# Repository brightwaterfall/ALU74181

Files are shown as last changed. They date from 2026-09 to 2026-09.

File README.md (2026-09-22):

  

# Tiny Tapeout — 74181 4-bit ALU

Digital Verilog **74181-style 4-bit ALU** for Tiny Tapeout (SKY130 / LibreLane).

**Repo:** https://github.com/brightwaterfall/ALU74181

- [Project documentation](docs/info.md)
- [Reproduce the flow](WALKTHROUGH.md)
- [Test PCB (auto S0–S3)](pcb/README.md)

## Status

| Check | Result |
|---|---|
| RTL cocotb (`test`) | Passing on GitHub Actions |
| GDS harden + precheck + GL test | Passing |
| Tagged release with GDS | See [Releases](https://github.com/brightwaterfall/ALU74181/releases) |

## Pin map

| Port | Signal |
|---|---|
| `ui_in[3:0]` | A[3:0] |
| `ui_in[7:4]` | B[3:0] |
| `uio_in[3:0]` | S[3:0] |
| `uio_in[4]` | M (1=logic, 0=arithmetic) |
| `uio_in[5]` | Cn_n (active-low carry in) |
| `uo_out[3:0]` | F[3:0] |
| `uo_out[4]` | AeqB |
| `uo_out[5]` | P_n |
| `uo_out[6]` | G_n |
| `uo_out[7]` | Cn4_n |

Top module: `tt_um_brightwaterfall_alu74181`

## Quick test

```bash
cd test
pip install -r requirements.txt
make
```

## What is Tiny Tapeout?

https://tinytapeout.com

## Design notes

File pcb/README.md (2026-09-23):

# 74181 ALU test PCB

Auto-exerciser for the Tiny Tapeout **74181 ALU** chip (`tt_um_brightwaterfall_alu74181`).

## Board preview

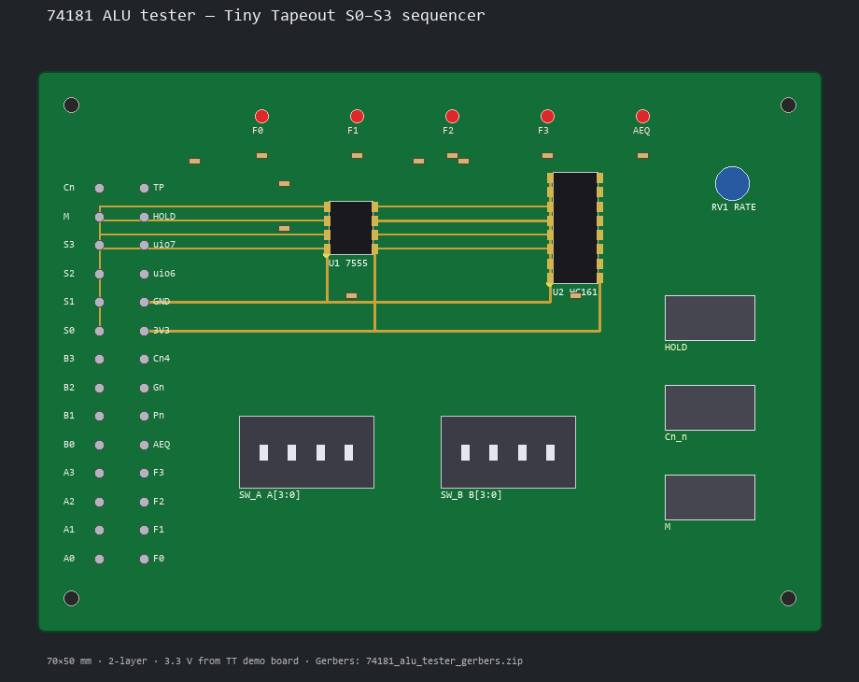
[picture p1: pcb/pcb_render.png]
PCB top view


## What it does

With **A**, **B**, **M**, and **Cn_n** on switches:

1. **7555/555** clocks a **74HC161**
2. **Q0–Q3 → S0–S3**
3. S runs **0→1→…→15→0…** (every function, one after another)
4. LEDs show **F[3:0]** and **AeqB**
5. **HOLD** freezes the current S value

Power and ground come from the **Tiny Tapeout demo board** (3.3 V). This PCB is an optional daughter / header harness — it does not replace the TT demo board.

## Fabrication (Gerbers ready)

| File | Purpose |
|---|---|
| **[74181_alu_tester_gerbers.zip](74181_alu_tester_gerbers.zip)** | Upload to JLCPCB / PCBWay |
| **[pcb_render.png](pcb_render.png)** | Top-view preview |
| [gerbers/](gerbers/) | Unpacked Gerber + Excellon |
| [generate_board.py](generate_board.py) | Regenerate Gerbers + preview (`py -3 generate_board.py`) |

**Board:** 70×50 mm · 2-layer · 1.6 mm · HASL · min track 0.25 mm

## Design docs

| File | Purpose |
|---|---|
| [BRINGUP.md](BRINGUP.md) | Power-on / usage |
| [SCHEMATIC.md](SCHEMATIC.md) | Net / wiring |
| [schematic_sequencer.svg](schematic_sequencer.svg) | Block schematic |
| [bom.csv](bom.csv) | BOM + LCSC hints |
| [connections.csv](connections.csv) | Header ↔ TT pins |
| `74181_alu_tester.kicad_pro` / `.kicad_sch` / `.kicad_pcb` | KiCad project shell (outline + notes) |

## Viewer (chip layout)

GitHub Pages + TT viewer: https://brightwaterfall.github.io/ALU74181/

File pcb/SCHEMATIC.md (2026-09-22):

# Schematic — 74181 ALU auto-S sequencer

Supply: **3V3** / **GND** from Tiny Tapeout demo board. All logic **74HC** @ 3.3 V.

## 1. Rate clock (555 astable)

| Ref | Value | Notes |
|-----|---|---|
| U1 | NE555 (or ICM7555) | Astable |
| R1 | 10 kΩ | |
| RV1 | 100 kΩ pot | Speed adjust |
| R2 | 10 kΩ | |
| C1 | 10 µF | ~0.5–10 Hz depending on pot |
| C2 | 100 nF | Control pin bypass |

Wiring (standard astable): discharge/threshold via R1+RV1/R2, C1 to GND, OUT → counter CLK.

## 2. S0–S3 sequencer (74HC161)

| Pin | Connection |
|-----|---|
| VCC / GND | 3V3 / GND |
| CLK | U1 OUT |
| ENT, ENP | 3V3 (count enable) |
| /LOAD | 3V3 (never parallel-load) |
| /CLR | 3V3 (no reset; free run 0–15) |
| A,B,C,D load inputs | GND |
| Q0 | **S0** → `uio[0]` |
| Q1 | **S1** → `uio[1]` |
| Q2 | **S2** → `uio[2]` |
| Q3 | **S3** → `uio[3]` |
| RCO | NC |

**HOLD** test point: pull **ENP** to GND through a switch to freeze S.

Sequence: `S = 0,1,2,…,15,0,…` — each value is one ALU function select, one after another.

## 3. Static ALU inputs (switches)

| Control | Destination | Default |
|---|---|---|
| DIP4 SW_A | `ui[0:3]` = A0…A3 | user |
| DIP4 SW_B | `ui[4:7]` = B0…B3 | user |
| SPDT SW_M | `uio[4]` = M | 3V3 = logic |
| SPDT SW_CN | `uio[5]` = Cn_n | 3V3 = carry inactive |

Each switch line: 10 kΩ pull-down to GND; switch to 3V3 closes = logic 1  
(or DIP with common GND and pull-ups — same idea). Use **10 kΩ** pull-downs + switch-to-3V3 for clarity.

`uio[6]`, `uio[7]`: tie to GND on the PCB.

## 4. Result LEDs (from chip)

| Source | Series R | LED |
|---|---|-----|
| `uo[0]` F0 | 330 Ω | LED0 |
| `uo[1]` F1 | 330 Ω | LED1 |
| `uo[2]` F2 | 330 Ω | LED2 |
| `uo[3]` F3 | 330 Ω | LED3 |
| `uo[4]` AeqB | 330 Ω | LED_AEQ |

Cathodes to GND (assuming active-high drive from TT outputs).

Optional: LEDs on Q0–Q3 (S) with 330 Ω for watching the function index.

## 5. Decoupling

- 100 nF on U1 VCC, U2 VCC to GND  
- 10 µF bulk on 3V3 entry

## 6. Connector `J_TT`

See [connections.csv](connections.csv). 2.54 mm male headers, one pin per signal + 3V3 + GND.

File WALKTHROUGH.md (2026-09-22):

# Walkthrough — clone to green Tiny Tapeout CI / harden

Repo: https://github.com/brightwaterfall/ALU74181

Verified on this project (push `403d9e8`):

| Workflow job | Result |
|---|---|
| `test` | success |
| `docs` | success |
| `gds` (LibreLane harden) | success |
| `precheck` | success |
| `gl_test` (gate-level) | success |
| `viewer` (GitHub Pages) | enable Pages under Settings → Pages → GitHub Actions, then re-run `gds` |

## 1. Clone

```bash
git clone https://github.com/brightwaterfall/ALU74181.git
cd ALU74181
```

## 2. RTL simulation (cocotb + Icarus)

```bash
cd test
pip install -r requirements.txt
make clean
make
# Pass: no <failure> / <error> in results.xml
```

Offline golden model (no Icarus):

```bash
pip install pytest
pytest test_golden_unit.py -q
```

## 3. Local harden (optional; same as CI `gds` job)

Requires Docker + Python 3.11+. Official guide: https://www.tinytapeout.com/guides/local-hardening/

```bash
git clone https://github.com/TinyTapeout/tt-support-tools tt
python3 -m venv ~/ttsetup/venv
source ~/ttsetup/venv/bin/activate   # Windows: ttsetup\venv\Scripts\activate
pip install -r tt/requirements.txt
export PDK_ROOT=~/ttsetup/pdk
export PDK=sky130A
export LIBRELANE_TAG=3.0.3           # match tt-gds-action default if updated
pip install librelane==$LIBRELANE_TAG

./tt/tt_tool.py --create-user-config
./tt/tt_tool.py --harden
./tt/tt_tool.py --print-warnings
./tt/tt_tool.py --create-png
```

Outputs land under `runs/` (GDS, LEF, netlist, PNG). CI uploads the same class of files as the `tt_submission` / `gds_render` artifacts.

> Note: older docs mention `make lf` (OpenLane). Current Tiny Tapeout SKY flow uses **LibreLane via `tt_tool.py --harden`** (what GitHub Actions runs).

## 4. GitHub Actions

On every push to `main`:

- **test** — cocotb RTL
- **gds** — harden + precheck + gate-level test + viewer
- **docs** — datasheet

Enable **Pages** (Settings → Pages → Deploy from GitHub Actions) so the viewer job can publish.

## 5. Tagged release with GDS

After a green `gds` run:

1. Download artifacts `tt_submission` and `gds_render` from the Actions run
2. Tag and publish:

```bash
git tag -a v1.0.0 -m "74181 ALU — TT harden artifacts"
git push origin v1.0.0
gh release create v1.0.0 --title "v1.0.0" --notes "Tiny Tapeout 74181 ALU GDS package" tt_submission.zip gds_render.png
```

## 6. Shuttle submission

1. https://app.tinytapeout.com/
2. Link `brightwaterfall/ALU74181`
3. Select shuttle / complete payment
4. Confirm automated checks are green

## 7. Test PCB

See [`pcb/`](pcb/). Auto-sequences **S0–S3** through all 16 functions; LEDs show **F**.

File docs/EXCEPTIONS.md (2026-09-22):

# Exceptional scenarios checklist

Hardening notes for operators / reviewers. Fixes applied in repo where noted.

| Scenario | Risk | Mitigation |
|---|---|---|
| Verilator `WIDTHEXPAND` on `cin` | Lint noise / subtle width bugs | Fixed: explicit `cin5` / `one` 5-bit operands |
| Arithmetic underflow (`(A&~B)-1` when 0) | Wrap to `0xF` | Defined 5-bit unsigned wrap; edge tests cover it |
| Floating `uio[6:7]` | Unknown inputs (unused) | Ignored in RTL; PCB ties to GND; drive 0 on demo board |
| `ena=0` (tile not selected) | Stale outputs | Wrapper forces `uo_out=0` when `ena=0` |
| Top module name collision | Shuttle ID clash | Renamed to `tt_um_brightwaterfall_alu74181` |
| Active-low `Cn_n` polarity mix-up | Off-by-one on add/sub | Documented; edge test `test_cn_polarity` |
| `M` wrong | Logic vs arithmetic swap | DIP labeled; docs table |
| Combo glitches on S counter edges | Brief wrong F on PCB | Expected for async S; slow 555 rate |
| Unused `clk`/`rst_n` | Lint unused | Tied in `_unused` reduction |
| P_n/G_n vs TTL datasheet | Not bit-exact CLA | F/Cn4/AeqB are primary; P/G for demo |
| Old GDS artifact name | Stale `tt_um_gddwms_*` files | Re-harden on CI after rename; new release |
| Gerber fab DRC | Scripted layout | Upload ZIP; run fab online DRC before order |
| GitHub Pages viewer | Deploy 404 | Pages enabled; viewer job green |
| CIR vs RTL | Transistor netlist ≠ gate RTL | CIR kept as reference only |

## Re-verify commands

```bash
cd test
pytest test_golden_unit.py test_edge_cases.py -q
python virtual_verify.py
# Full RTL (needs Icarus): make
```

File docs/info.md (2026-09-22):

<!---
Tiny Tapeout datasheet content for the 74181 ALU project.
-->

## How it works

This project implements a classic **74181-style 4-bit ALU** in synthesizable Verilog for Tiny Tapeout.

- **Logic mode (`M=1`)**: 16 bitwise functions of `A` and `B` selected by `S[3:0]` (NOT, NOR, XOR, AND, OR, pass-through, constants, …), matching the TI active-high data table.
- **Arithmetic mode (`M=0`)**: add / subtract / increment-style operations. Carry-in pin `Cn_n` is **active-low** (TTL naming): drive `Cn_n=0` to assert carry-in.
- Outputs: result `F[3:0]`, equality `AeqB` (high when `F==4'hF`), and active-low look-ahead / carry signals `P_n`, `G_n`, `Cn4_n`.

The design is **combinational** (no clocked state). `clk` / `rst_n` are unused and tied off inside the top module.

A transistor-level SPICE netlist (`74181.cir`) was used as the architectural reference for the ALU function; the shuttle payload is this digital RTL so it fits the Tiny Tapeout digital flow (LibreLane harden + CI).

## How to test

1. Set `A` on `ui_in[3:0]` and `B` on `ui_in[7:4]`.
2. Set function select `S` on `uio_in[3:0]`, mode `M` on `uio_in[4]`, carry-in `Cn_n` on `uio_in[5]`.
3. Read `F` on `uo_out[3:0]` and status flags on `uo_out[7:4]`.

Examples:

| Mode | S | Cn_n | Operation |
|---|---|---|---|
| M=1 | `1111` | x | `F = A` |
| M=1 | `0110` | x | `F = A XOR B` |
| M=0 | `1001` | 1 | `F = A + B` |
| M=0 | `1001` | 0 | `F = A + B + 1` |
| M=0 | `0110` | 0 | `F = A - B` |

Automated checks: from `test/`, run `make` (cocotb + Icarus).

## External hardware

- Tiny Tapeout demo board (host for the ASIC tile)
- **74181 ALU test PCB** (`pcb/`): 555 + 74HC161 auto-sequences **S0–S3** through all 16 functions; DIP switches set A/B/M/Cn_n; LEDs show F and AeqB. See `pcb/README.md` and `pcb/BRINGUP.md`.

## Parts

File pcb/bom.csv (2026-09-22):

Comment | Designator | Footprint | Qty | LCSC (typical) | Notes
ICM7555 / NE555 | U1 | SOIC-8 | 1 | C14663 | Prefer CMOS 7555 at 3.3V
74HC161 | U2 | SOIC-16 | 1 | C5595 | Binary counter for S[3:0]
100k pot | RV1 | Pot 9mm | 1 | C118933 | Sequence rate
10k 0603 | R1 R2 RA0-3 RB0-3 RM RCN | 0603 | 12 | C17408 | 555 + pull-downs
330 0603 | RF0-3 RAEQ | 0603 | 5 | C17561 | LED series
10uF 0805 | C1 CBULK | 0805 | 2 | C15850 | Timing + bulk
100nF 0603 | C2 CD1 CD2 | 0603 | 3 | C14663 | Bypass (match stock)
LED red 0805 | LED_F0-3 LED_AEQ | 0805 | 5 | C84264 | F and AeqB
DIP switch 4 | SW_A SW_B | DIP-4 | 2 | C202577 | A and B operands
SPDT slide | SW_M SW_CN SW_HOLD | PTH slide | 3 | — | M / Cn_n / freeze
Header 2.54 1x20 | J_TT | PTH | 1 | — | Wire to TT demo board

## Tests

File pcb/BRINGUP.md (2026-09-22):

# Bring-up — 74181 ALU function sequencer PCB

## Hookup

1. Power **off** the Tiny Tapeout demo board.
2. Connect `J_TT` on this PCB to the demo board pins per [connections.csv](connections.csv)
   (ribbon or DuPont jumpers: `ui_*`, `uo_*`, `uio_*`, `3V3`, `GND`).
3. Set **DIP A** and **DIP B** to the operands you want (example: A=`0101`, B=`0011`).
4. Set **M**:
   - `M=1` (switch toward 3V3): logic functions for each S
   - `M=0` (toward GND): arithmetic functions for each S
5. Set **Cn_n** (active-low carry in):
   - open / high = no extra +1 on arithmetic
   - low = carry-in asserted
6. Power on the demo board (select this project’s tile if required).
7. Adjust **RV1** (rate pot): S should step visibly; F LEDs change on every count.

## What you should see

- Four **S LEDs** (optional on Q0–Q3) or a logic probe on `uio[0:3]` count binary 0…15 and wrap.
- **F LEDs** update immediately after each S step (combinational ALU).
- **AeqB LED** lights when `F == 4'hF`.

No firmware, no MCU — only 555 + 74HC161.

## Stop / hold one function

- Ground **HOLD** (ties 74HC161 clock enable low) to freeze on the current S.
- Or remove the 555 output jumper and drive S from an external pattern later if needed.

## Troubleshooting

| Symptom | Check |
|---|---|
| No LED activity | 3V3/GND, tile selected, F LED polarity/resistors |
| S not changing | 555 output, ENT/ENP high, /CLR high, HOLD not grounded |
| Wrong F for expected S | M/Cn_n/A/B switches; confirm pin map vs `info.yaml` |

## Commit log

2026-09-22 Convert to digital Tiny Tapeout flow and add 74181 ALU RTL.
    Replace the analog template with the SKY130 Verilog template, implement
    tt_um_gddwms_alu74181 with cocotb tests, docs, and walkthrough.
2026-09-22 Complete local TT package: golden tests, PCB stub, walkthrough.
    Add offline pytest model checks (no Icarus), pcb placeholder, and clarify
    local vs CI simulation steps. No remote push.
2026-09-22 Add ALU test PCB that auto-sequences S0-S3 through all functions.
    555 + 74HC161 cycles function select; DIP for A/B/M/Cn; LEDs for F.
    [74181_alu_tester.kicad_sch, bom.csv, connections.csv]
2026-09-22 Complete project docs, PCB schematic SVG, and release prep.
    Update walkthrough with verified CI results and LibreLane harden steps;
    refresh PCB BOM/SVG; set author to brightwaterfall.
    [bom.csv]
2026-09-22 Add fab Gerber package for ALU S-sequencer PCB.
    Generate 70x50mm 2-layer Gerbers/Excellon ZIP for JLCPCB and KiCad PCB outline.
    [74181_alu_tester.kicad_pcb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]
2026-09-22 Track Gerber ZIP for PCB fab upload
2026-09-22 Harden RTL against width/ena/name edge cases.
    Use explicit 5-bit arithmetic, gate outputs when ena=0, rename top
    module to tt_um_brightwaterfall_alu74181, add edge-case tests.
2026-09-23 Add full 74181 tester PCB layout, Gerbers, and board preview.
    [74181_alu_tester.kicad_pcb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]
